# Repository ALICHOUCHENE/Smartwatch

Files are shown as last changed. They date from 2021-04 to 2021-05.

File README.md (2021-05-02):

<div align="center"><h1 style="font-family: courier;" align="center"></h1></div>

# Description
Smartwatch circuit for health and fitness
This robust fitness watch was designed for football players who leads an active lifestyle and values health and well-being. 
The watch creates for a personal training plan that adapts to some fitness needs. 
This smart-watch will provide a real-time guidance while exercising to help the player at the right intensity.
24/7 activity tracking with steps, calories and sleep, together with stress and recovery monitoring, provide a real time heart rate monitoring and help to maintain a healthy balance between activity and rest.

Here the features of the board:

- Xtensa dual-core 32-bit LX6 microprocessor(WROOM-32D) is the CPU of the board. operating at 240 MHz.
- Optical Sensor IC,BH1792GLC, a heart rate monitor module integrated with LED driver, green light, and IR detection photodiode.
- 1Cell / 3.7V 230mA Battery Management System / BMS Over Voltage, Over Current, Short Circuit Protection Module for Lithium ION Batterie.
- UART programming interface.
- I2C interface for OLED display.
- USB port for charging.

# PCB Layout : 

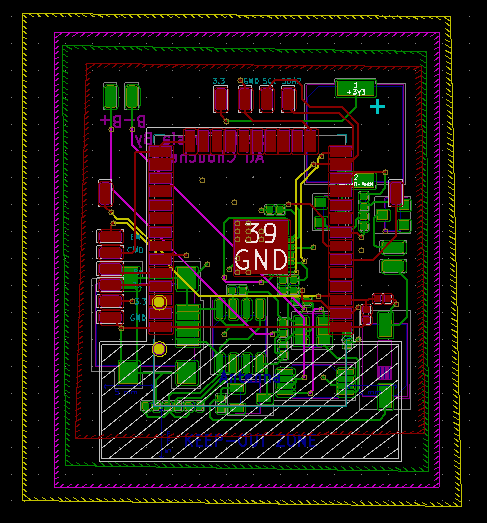
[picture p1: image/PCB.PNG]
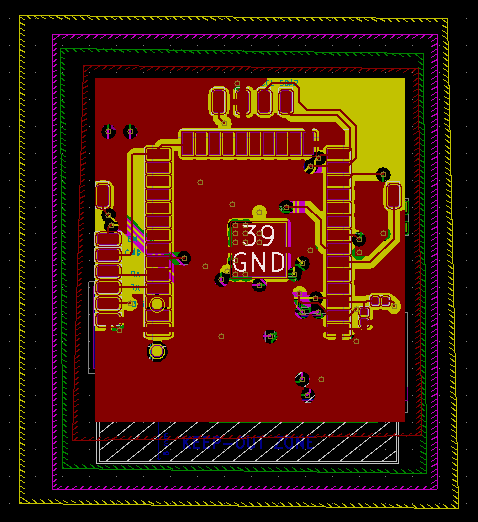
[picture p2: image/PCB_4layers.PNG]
 

# Board 3D view : 

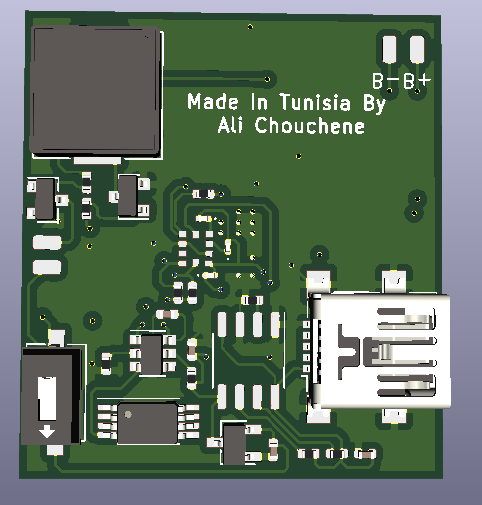
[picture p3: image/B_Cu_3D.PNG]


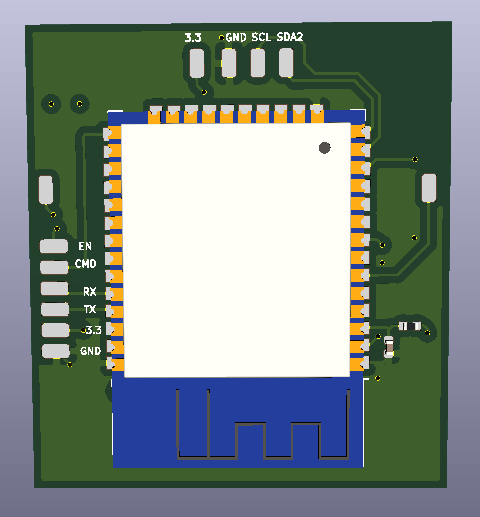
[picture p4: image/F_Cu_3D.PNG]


# Final Poduct : 

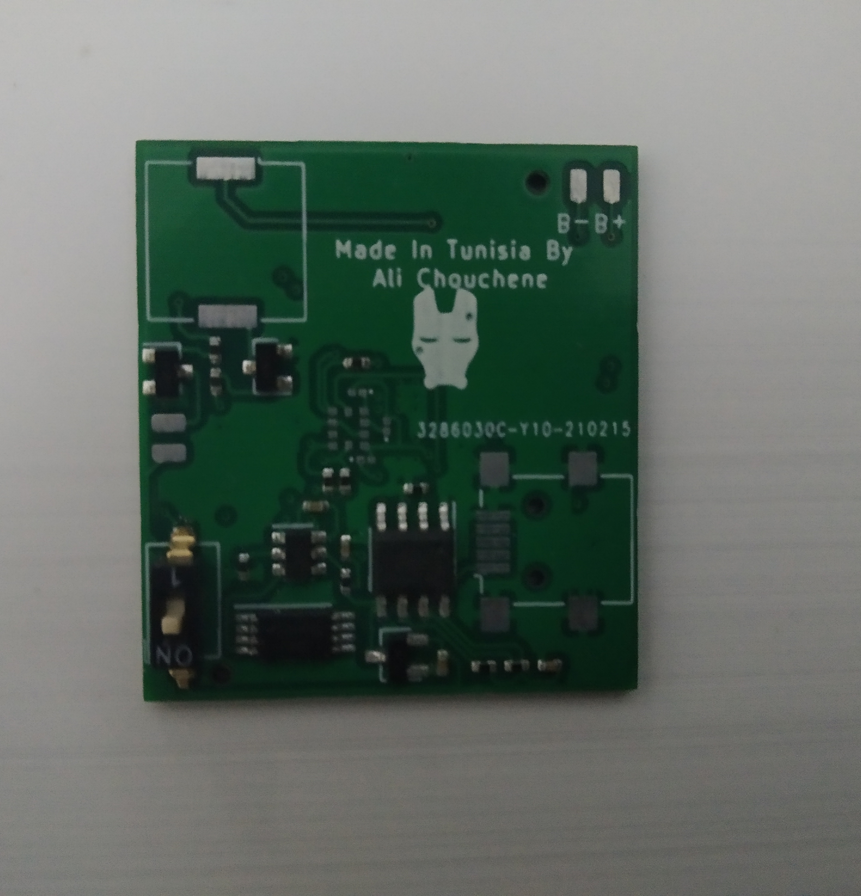
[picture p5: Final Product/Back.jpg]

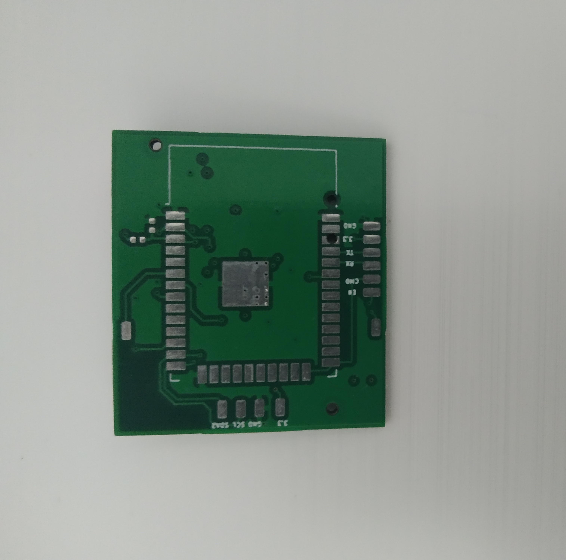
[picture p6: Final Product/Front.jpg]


 # Manufacturing
 
After finishing the Routing and verify the pcb. We made the board at JLC PCB and we chose also the PCB Assembly service.
Here is the **[BOM](https://github.com/ALICHOUCHENE/Smartwatch-/blob/main/Assembly/BOM.csv)** needed for jlcpcb assembly service:

| Designator | Value | Footprint | LCSC Part |
|---|---|---|---|
| U2 | TP4056 | Package_SO:SO-8_3.9x4.9mm_P1.27mm | C16581 |
| R5 | 1.2K | 402 |  C25862 |
| R7 | 1K | 402 | C11702 |
| R8 | 1K | 402 | C11702 |
| R4 | 1K | 402 | C11702 |
| C2 | 0.1UF | 402 |  C1525 |
| R6 | 100 | 402 |  C25076 |
| C3 | 0.1UF | 402 |  C1525 |
| U1 | FS8205A | Package_SO:TSSOP-8_4.4x3mm_P0.65mm | C16052 |
| R2 | 3.3K | 402 |  C25890 |
| R3 | 3.3K | 402 |  C25890 |
| R1 | 3.3K | 402 |  C25890 |
| C4 | 100nF | 402 |  C1525 |
| R9 | 10K | 402 |  C25744 |
| U4 | ESP32-WROOM-32D | RF_Module:ESP32-WROOM-32 | |
| U3 | DW01-P | Package_TO_SOT_SMD:SOT-23-6 | C181096 |
| C1 | 0.1UF | 402 |  C1525 |
| J1 | USB_OTG | Connector_USB:USB_Mini-B_Lumberg_2486_01_Horizontal | C136451 |
| BZ1 | Buzzer | Buzzer_Beeper:Buzzer_Murata_PKMCS0909E4000-R1 | C255319 |
| R11 | 330 | 402 |  C25104 |
| R10 | 330 | 402 |  C25104 |
| SW1 | SW_DIP_x01 | Button_Switch_SMD:SW_DIP_SPSTx01_Slide_6.7x4.1mm_W6.73mm_P2.54mm_LowProfile_JPin | C54948 |
| D2 | LED | 402 | |
| D4 | LED | 402 | |
| D3 | LED | 402 | |
| Q2 | BC847 | Package_TO_SOT_SMD:SOT-23 | C8664 |
| Q3 | BC847 | Package_TO_SOT_SMD:SOT-23 | C8664 |
| U5 | AMS1117-3.3 | Package_TO_SOT_SMD:TSOT-23 | C83932 |
| C5 | 0.1UF | 402 |  C1525 |

# Downloads

* [Board schematics](https://github.com/ALICHOUCHENE/Smartwatch-/blob/main/Schematic.pdf)

* [PCB layout](https://github.com/ALICHOUCHENE/Smartwatch-/blob/main/Smartwatch.kicad_pcb)

* [BOM](https://github.com/ALICHOUCHENE/Smartwatch-/blob/main/Assembly/BOM.csv)

* [Position file](https://github.com/ALICHOUCHENE/Smartwatch-/blob/main/Assembly/Smartwatch-all-pos.csv)

* [Gerber File](https://github.com/ALICHOUCHENE/Smartwatch-/blob/main/Gerber/Gerber.rar)

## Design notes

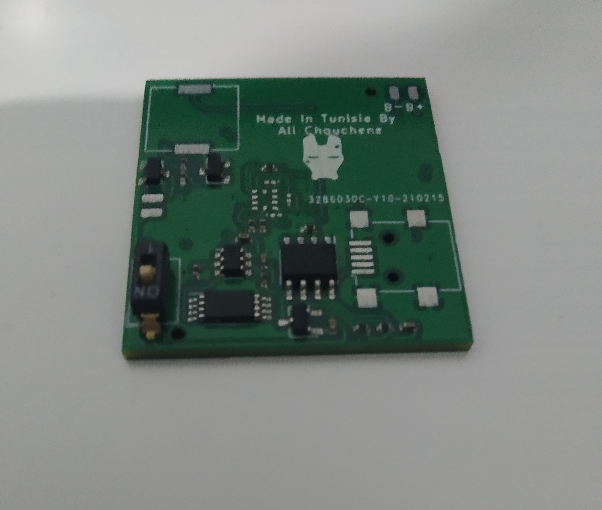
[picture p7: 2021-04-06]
Final Product/Board.jpg

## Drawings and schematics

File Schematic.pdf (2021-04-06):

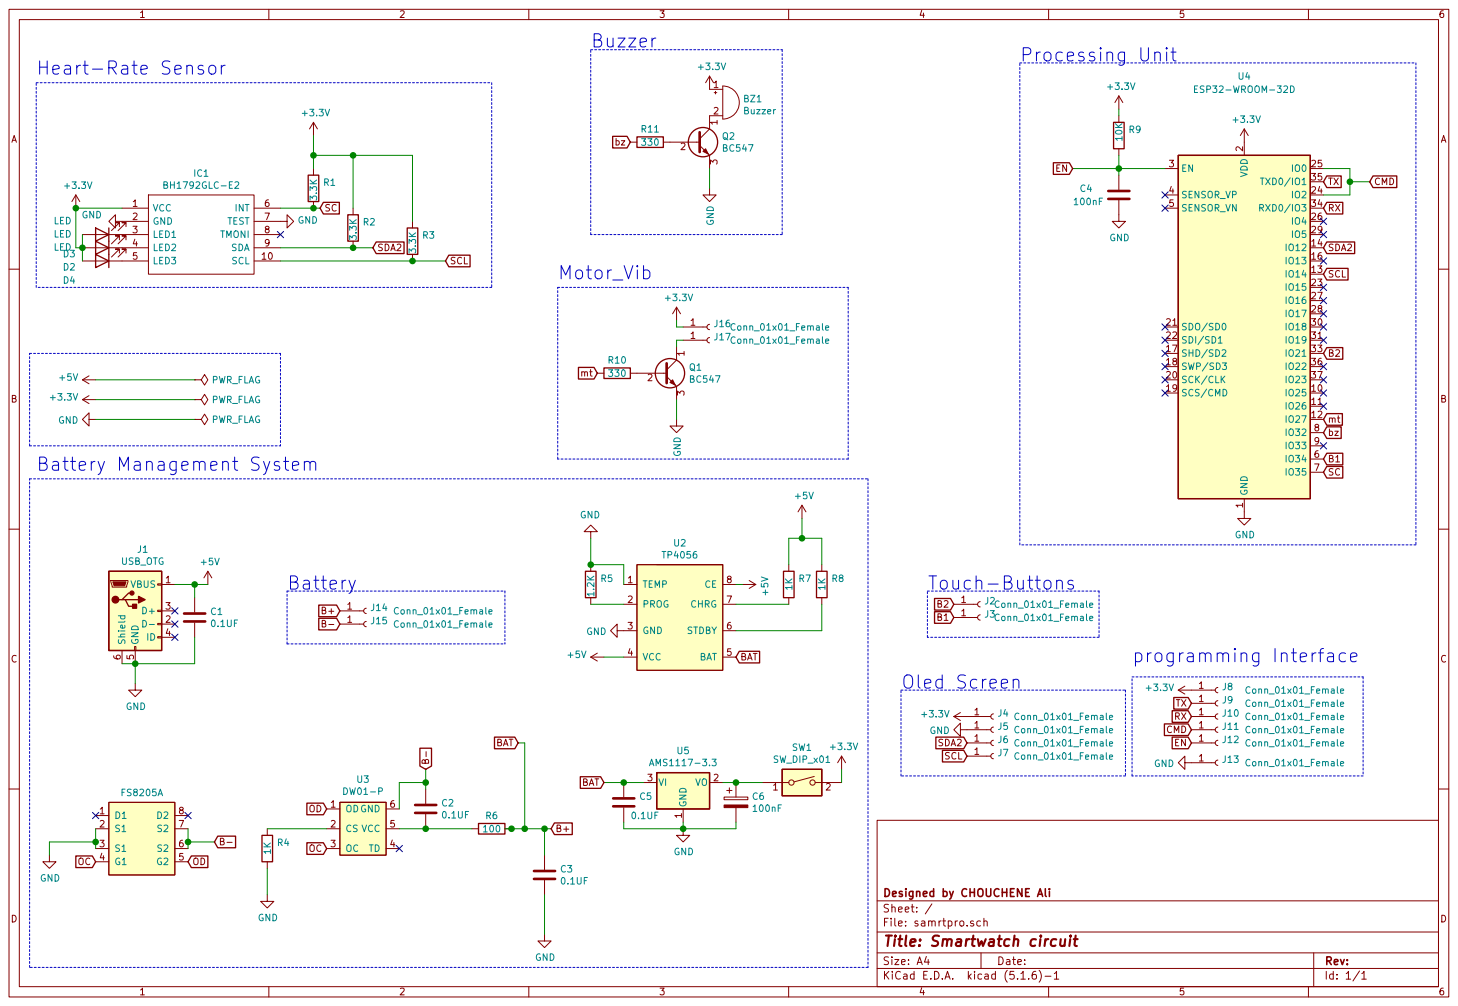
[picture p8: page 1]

2 SCK/CLK 20 SDO/SD0 21 SDI/SD1 22

File: samrtpro.sch Sheet: / Designed by CHOUCHENE Ali

Id: 1/1 Title: Smartwatch circuit

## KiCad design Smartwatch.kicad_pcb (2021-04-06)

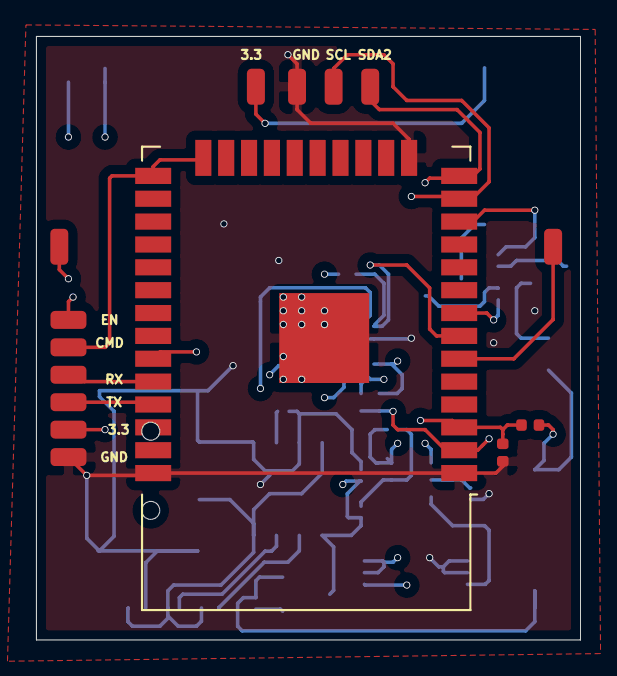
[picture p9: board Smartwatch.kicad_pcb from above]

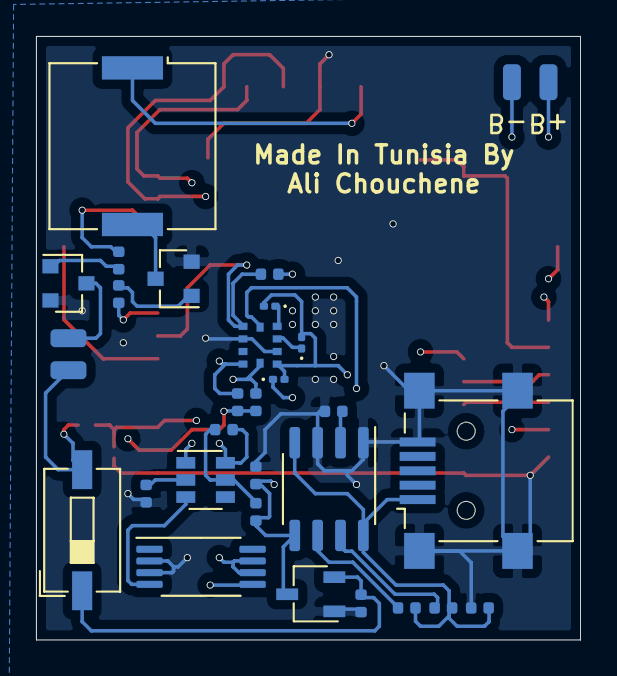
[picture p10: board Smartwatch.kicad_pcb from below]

Board: 4 copper layers, 30.2 x 33.5 mm, 46 parts (31 on the bottom side), 31 nets.

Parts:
BZ1: Buzzer; Buzzer_Murata_PKMCS0909E4000-R1
C1, C2, C3, C5: 0.1UF; C_0402_1005Metric
C4: 100nF; C_0402_1005Metric
D2, D3, D4: LED; LED_0201_0603Metric
IC1: BH1792GLC-E2; WLG
J1: USB_OTG; USB_Mini-B_Lumberg_2486_01_Horizontal
J2, J3, J4, J5, J6, J7, J8, J9, J10, J11, J12, J13, J14, J15, J16, J17: Conn_01x01_Female; SolderWirePad_1x01_SMD_1x2mm
Q2, Q3: BC847; SOT-23
R1, R2, R3: 3.3K; R_0402_1005Metric
R4, R7, R8: 1K; R_0402_1005Metric
R5: 1.2K; R_0402_1005Metric
R6: 100; R_0402_1005Metric
R9: 10K; R_0402_1005Metric
R10, R11: 330; R_0402_1005Metric
SW1: SW_DIP_x01; SW_DIP_SPSTx01_Slide_6.7x4.1mm_W6.73mm_P2.54mm_LowProfile_J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
U1: FS8205A; TSSOP-8_4.4x3mm_P0.65mm
U2: TP4056; SO-8_3.9x4.9mm_P1.27mm
U3: DW01-P; SOT-23-6
U4: ESP32-WROOM-32D; ESP32-WROOM-32
U5: AMS1117-3.3; TSOT-23

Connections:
+3V3: BZ1.1, D2.2, D3.2, D4.2, IC1.1, J4.1, J8.1, J16.1, R1.1, R2.1, R3.1, R9.1, SW1.2, U4.2
+5V: C1.1, J1.1, R7.1, R8.1, U2.4, U2.8
B1: J3.1, U4.6
B2: J2.1, U4.33
B+: C3.1, J14.1, R6.1, U2.5, U5.3
B-: C2.1, J13.1, U1.6, U1.7, U3.6
CMD: J11.1, U4.24, U4.25
EN: C4.1, J12.1, R9.2, U4.3
GND: C1.2, C3.2, C4.2, C5.2, IC1.2, IC1.7, J1.5, J1.6, J5.1, J15.1, Q2.2, Q3.2, R4.2, R5.1, U1.2, U1.3, U2.1, U2.3, U4.1, U4.15, U4.38, U4.39, U5.1
unnamed: BZ1.2, Q3.3
unnamed: C2.2, R6.2, U3.5
unnamed: C5.1, SW1.1, U5.2
unnamed: D2.1, IC1.3
unnamed: D3.1, IC1.4
unnamed: D4.1, IC1.5
unnamed: J17.1, Q2.3
unnamed: Q2.1, R10.1
unnamed: Q3.1, R11.1
unnamed: R4.1, U3.2
unnamed: R5.2, U2.2
unnamed: R7.2, U2.7
unnamed: R8.2, U2.6
OC: U1.4, U3.3
OD: U1.5, U3.1
RX: J10.1, U4.34
SC: IC1.6, R1.2, U4.7
SCL: IC1.10, J7.1, R3.2, U4.13
SDA2: IC1.9, J6.1, R2.2, U4.14
TX: J9.1, U4.35
bz: R11.2, U4.8
mt: R10.2, U4.12

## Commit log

2021-04-06 Create schematic
2021-04-06 Create Assembly
